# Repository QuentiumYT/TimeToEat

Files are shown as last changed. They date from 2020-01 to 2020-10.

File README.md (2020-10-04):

<h1 align="center">TimeToEat Project ⏰</h1>

Website (https://timetoeat.alwaysdata.net)&nbsp;
Donate (https://www.paypal.me/QuentiumYT/1)&nbsp;
Computer (https://www.raspberrypi.org/products/raspberry-pi-3-model-b/)&nbsp;
Tested on Python 3.5 (https://www.python.org/downloads)&nbsp;
Tested on Browsers&nbsp;
Application (https://timetoeat.alwaysdata.net/application/TimeToEat.apk)&nbsp;
Assets (https://www.solidworks.com/)&nbsp;
License&nbsp;
&nbsp;

## ✨ Introduction

<p align="center">
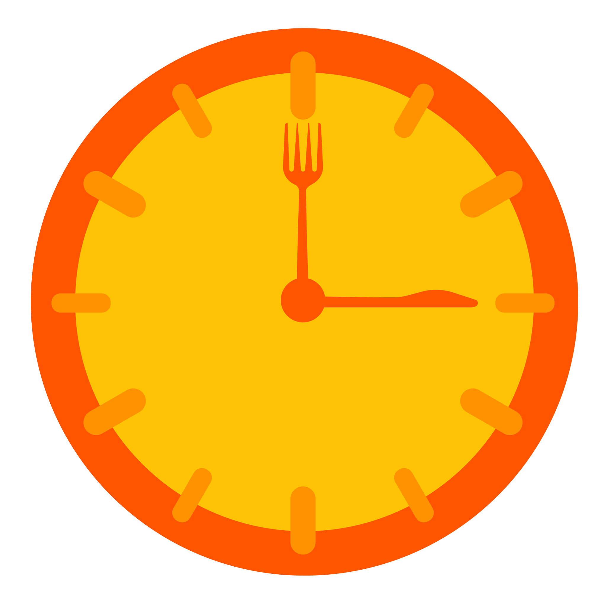
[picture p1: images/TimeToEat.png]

</p>

#### TimeToEat is a project for my final high school year exam (June 2019)

The idea for this project came to us when we noted the rather long waiting time in the canteen queue. So we decided to create a system to know the waiting time remaining as well as the number of people in the queue to be able to optimize its passage time.

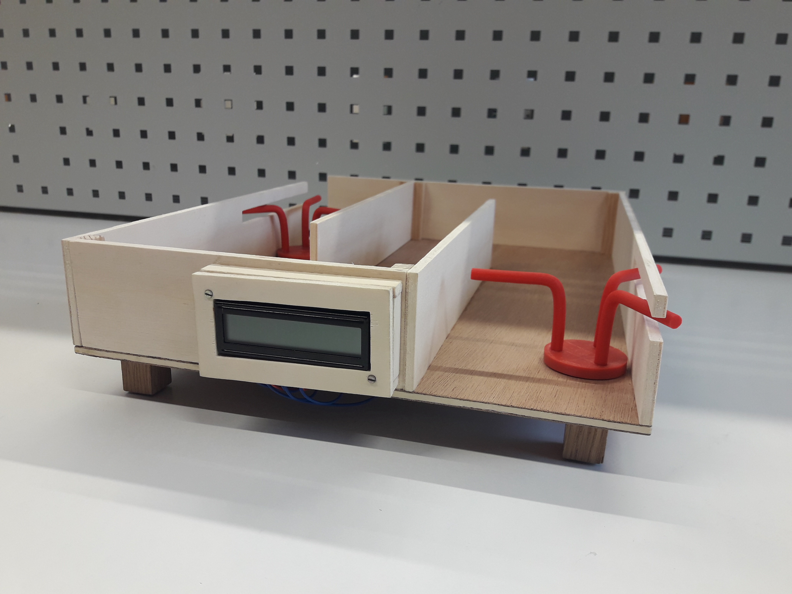
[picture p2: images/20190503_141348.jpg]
TimeToEat Model


You can find scripts `python/main.py` alongside `python/constantes.py` used on the raspberry to communicate with LCD and the [website](https://timetoeat.tk), you can always check the code but this project is very specific to a model we've made so you might find it useless.

This was a great first project with 2 of my close friends and we managed to get a good mark for this exam thanks to organization and work we've done :D

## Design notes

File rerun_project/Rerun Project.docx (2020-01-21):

Bonjour,

Je me permets de vous contacter pour vous joindre les fichiers de nôtre projet TimeToEat (en l’occurrence les miens) qui vous serviraient potentiellement à faire fonctionner le projet à nouveau.

Vu que la maquette se trouve encore au lycée, je me suis dit qu’il vous serait peut-être utile d’avoir un fonctionnement possible grâce aux fichiers et à la configuration de la Raspberry.

Si vous voulez donc remettre en marche ce projet, il vous faudra télécharger l’archive ci-jointe contenant les scripts pour la Raspberry (une image exacte de la Raspberry serait trop complexe à remettre en place car il risquerait d’y avoir des différences au niveau hardware).

MATERIEL RECOMMANDE :

-Raspberry pi 3

-Raspbian OS

-Carte SD : 4GB → Image sans desktop

8GB → Image avec desktop

CABLAGE DE LA MAQUETTE A LA RASPBERRY :

Vous trouverez l’image « TimeToEat_Wiring » ci-dessous pour avoir une vue d’ensemble, pour câbler la maquette il faut décaler le domino de 1 pin pour chacun des 2 (voir « TimeToEat_Brooch » pour la version simplifiée). La grosse broche (LCD) doit avoir le câble noir vers l’intérieur et la petite broche doit avoir le câble rouge vers l’extérieur.

CONFIGURATION RASPBERRY :

Si vous utilisez une nouvelle image de Rapsbian (téléchargement sur leur site), éditez /etc/dhcpcd.conf avec les paramètres réseaux (IP libre utilisée 10.129.104.127) puis communiquez avec WinSCP pour déplacer les fichiers joints dans l’archive RAR vers la raspberry (/home/pi/).

Vous devez déplacer « constantes.py » / « main.py » pour le fonctionnement mais aussi « pip.sh » et potentiellement « TimetoEat.sh » pour automatiser le fonctionnement instantané du projet.

Lancez Putty et installez les packages suivants :

AVEC « pip.sh » dans le dossier racine :

$ sudo bash pip.sh <nom du package>

SANS « pip.sh » dans le dossier racine :

$ sudo pip3 install --proxy=10.129.254.254:3128 <nom du package>

PACKAGES A INSTALLER :

« RPLCD » / « RPi.GPIO » / « requests » / « dotenv »

Si le package « RPi.GPIO » échoue, veuillez exécuter cette commande :

$ sudo apt-get -y install python3-rpi.gpio

Une fois les packages installés vous pouvez déjà lancer le projet, or, il vous faudra le relancer manuellement à chaque redémarrage de la raspberry.

DEMARRAGE MANUEL :

Tapez dans le terminal :

$ sudo python3 main.py

Le script devrait afficher des choses sur l’écran et commencer à tourner.

REDEMARRAGE AUTOMATIQUE :

Pour que le projet se lance au branchement secteur de la Raspberry, vous aurez besoin du package linux nommé « screen » :

- sudo apt-get -y install screen

Vous devrez ensuite posséder le fichier « TimeToEat.sh » dans le dossier racine (/home/pi/), dans ce cas, exécutez les commandes suivantes :

$ sudo mv TimeToEat.sh /etc/init.d/

$ cd /etc/init.d/

$ sudo chmod 777 TimeToEat.sh

$ sudo update-rc.d TimeToEat.sh defaults

Puis rebootez la Raspberry. S’il n’y a pas d’erreurs, tout devrait fonctionner comme à la soutenance de notre projet. Sinon, n’hésitez pas à me recontacter en cas de soucis.

Pour ce qui en est du site web, il sera toujours accessible via « https://timetoeat.alwaysdata.net/ » et restera actif via « https://timetoeat.xyz/ » jusqu’en mars (nom de domaine acheté bientôt expiré). Si le projet tourne, le seul changement sur le site sera dans la partie Temps réel.

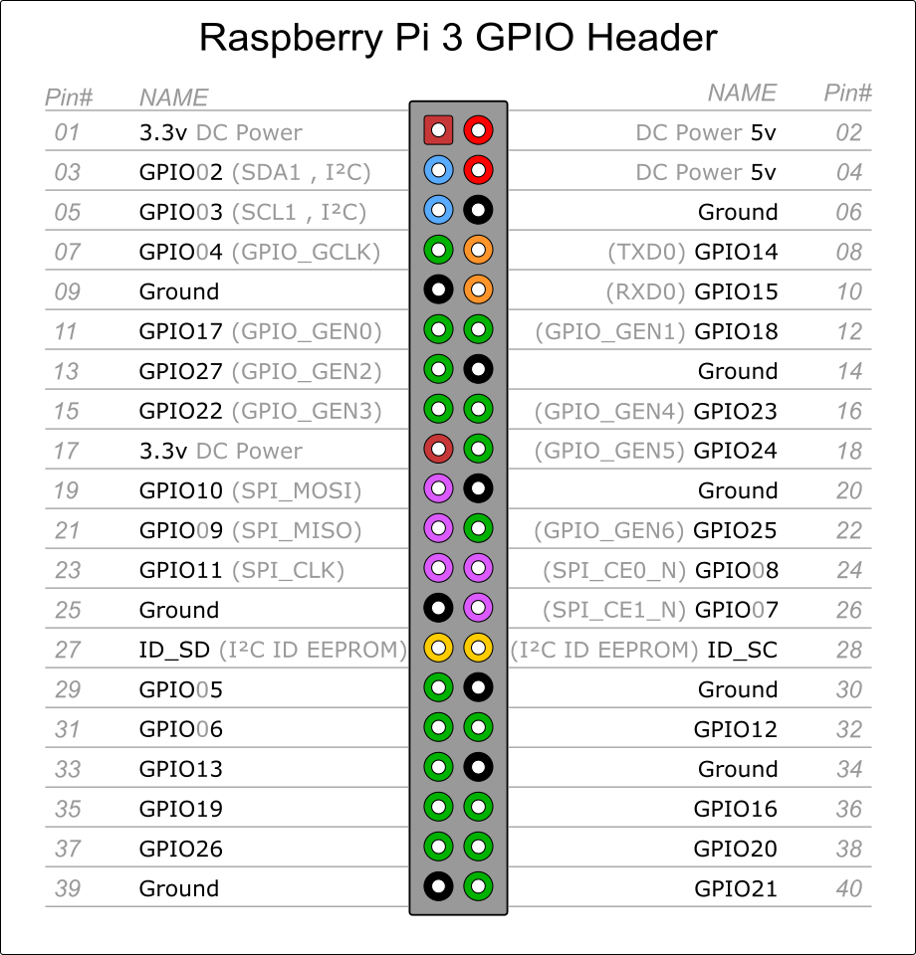
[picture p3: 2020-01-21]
images/Raspberry_Pi_GPIO_Layout.png

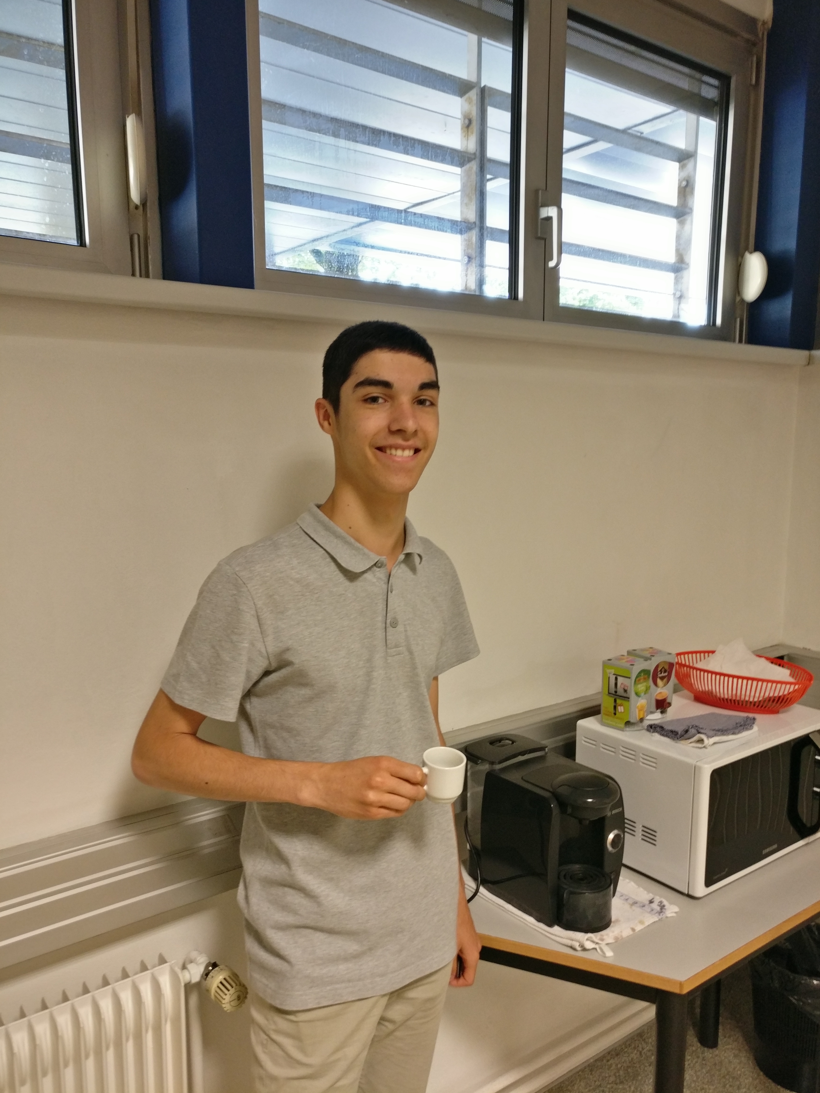
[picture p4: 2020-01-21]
web/img/quentin.jpg

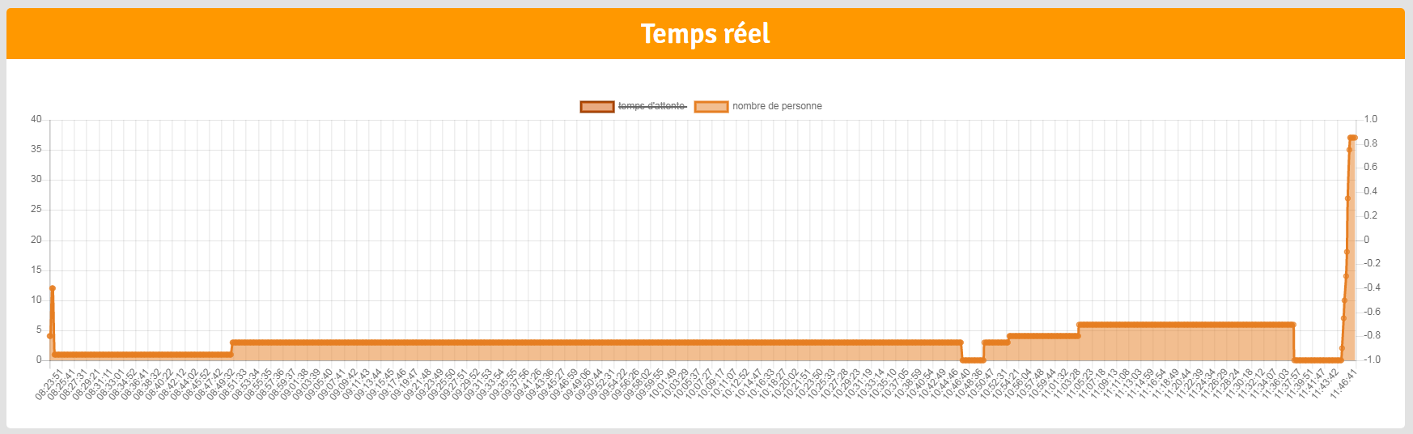
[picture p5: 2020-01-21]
images/Temps réel 2.png

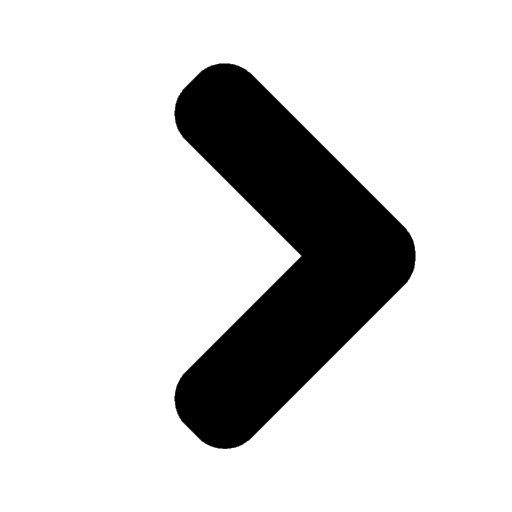
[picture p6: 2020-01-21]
web/img/arrow_right.png

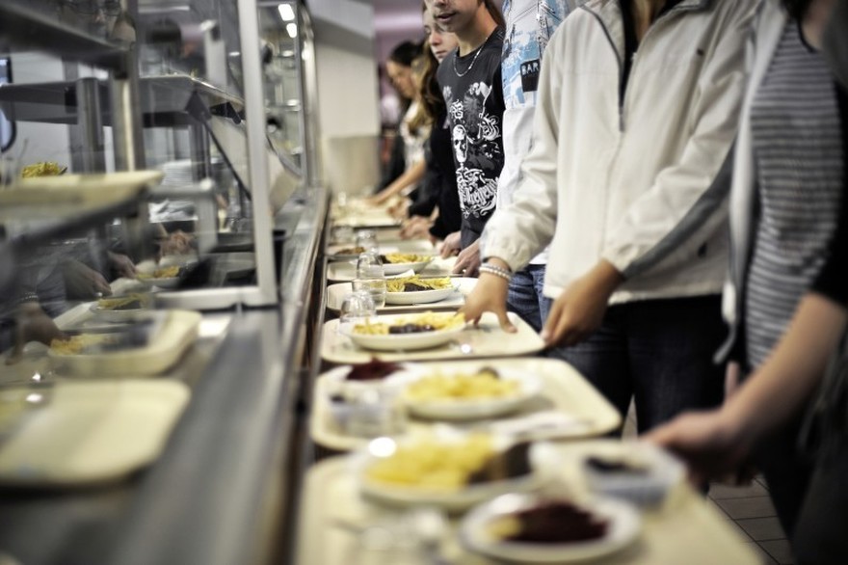
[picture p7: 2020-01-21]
web/img/cantine.jpg

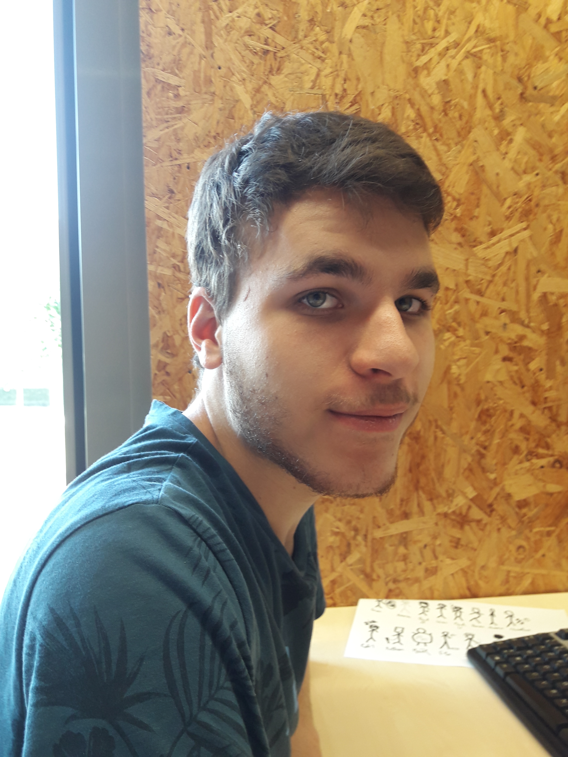
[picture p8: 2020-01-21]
web/img/nicolas.jpg

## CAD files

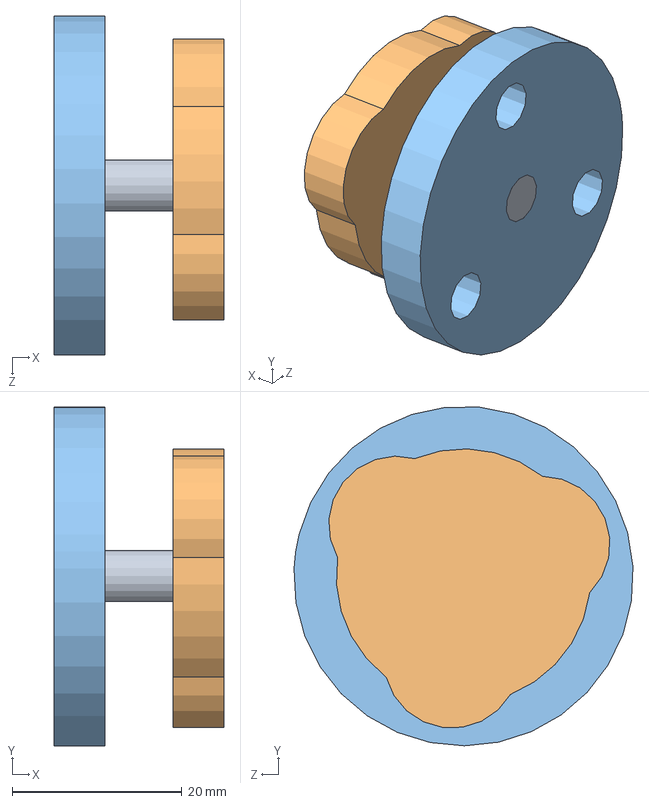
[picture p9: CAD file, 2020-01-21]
turnstile_solidworks/Assemblage2.SLDASM
20.0 x 39.9 x 39.9 mm
axe
came
tourniquet

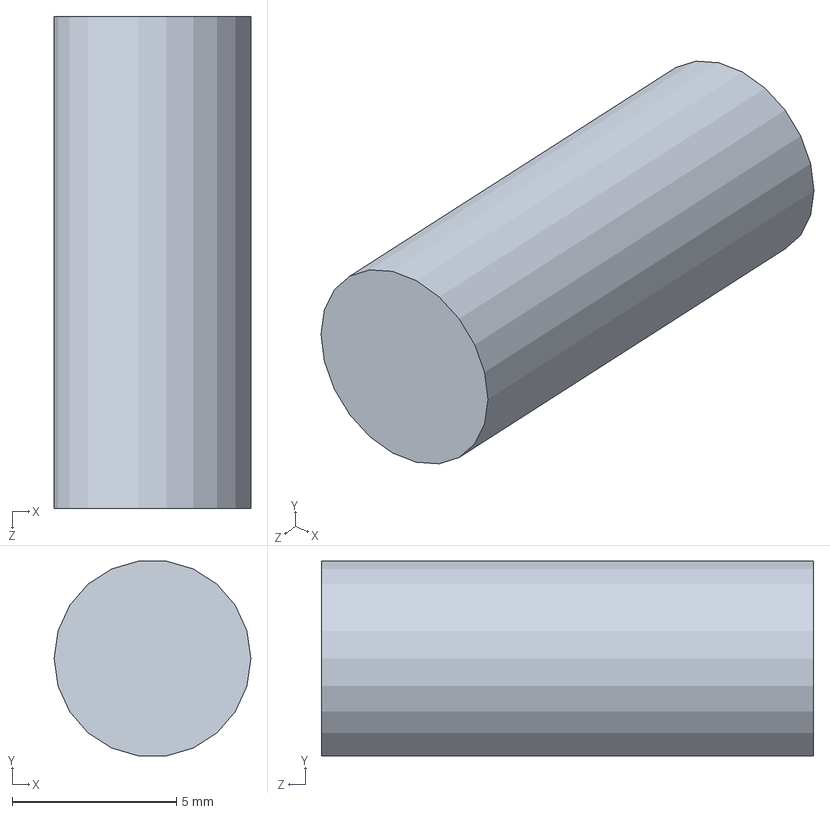
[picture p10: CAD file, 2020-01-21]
turnstile_solidworks/axe2.SLDPRT
6.00 x 5.94 x 15.0 mm

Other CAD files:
turnstile_solidworks/Module.SLDASM
turnstile_solidworks/mur-central.SLDPRT
turnstile_solidworks/Microrupteur.SLDPRT
turnstile_solidworks/sol.SLDPRT
turnstile_solidworks/tourniquet.SLDPRT
turnstile_solidworks/mur-exterieur.SLDPRT
turnstile_solidworks/mur2.SLDPRT
turnstile_solidworks/mur1.SLDPRT
turnstile_solidworks/barre-de-passage.SLDPRT
turnstile_solidworks/came.SLDPRT
turnstile_solidworks/axe.SLDPRT
turnstile_solidworks/axe2.STL

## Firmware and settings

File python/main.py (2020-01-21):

from RPLCD import CharLCD # Module pour l'ecran LCD
from RPi import GPIO # Module pour les pins
from datetime import datetime # Module pour le temps (timer)
import threading, time, calendar, requests, random # Autres modules complémentaires

from constantes import * # Importation des constantes / pins / charactères spéciaux

# Réglages pour GPIO
GPIO.setwarnings(False)
GPIO.setmode(GPIO.BOARD)
GPIO.setup(pins_data_count, GPIO.IN, pull_up_down=GPIO.PUD_DOWN) # Mode des microrupteurs

# Définition de l'écran LCD
lcd = CharLCD(numbering_mode=GPIO.BOARD,
              cols=16, rows=2, pin_rs=37, pin_e=35,
              pins_data=pins_data_lcd, charmap="A02")

# Fonction de cryptage
def cryptage(chaine, cle):
    global alpha
    liste = ""
    for caractere in chaine:
        try:
            index = alpha.index(caractere)
            numero = index + cle
            cle = cle + cle
            if cle > len(alpha) - 1:
                cle = cle - len(alpha) - 1
            if numero > len(alpha) - 1:
                numero = numero - len(alpha)
            liste += alpha[numero]
        except:
            liste += caractere
    return liste

# Affichage des données sur l'écran LCD
def write_on_lcd(nb_people, nb_flow, state):
    global old_nb_people, old_nb_flow
    lcd.clear()
    lcd.cursor_pos = (0, 0) # Position initiale
    if state == "+": # Personne rejoins
        state = " \2"
    elif state == "-": # Personne quitte
        state = " \3"
    elif state == "*": # Débit affiché
        state = " \4"
    if not nb_people == "None":
        lcd.write_string("Personnes: " + str(nb_people) + state)
        old_nb_people = nb_people #Définition de l'ancienne valeur des personnes
    else:
        lcd.write_string("Personnes: " + str(old_nb_people) + state)
    lcd.cursor_pos = (1, 0)
    if not nb_flow == "None":
        lcd.write_string("D\1bit: {}/min".format(str(nb_flow)))
        old_nb_flow = nb_flow # Définition de l'ancienne valeur du débit
    else:
        lcd.write_string("D\1bit: {}/min".format(str(old_nb_flow)))
    lcd.write_string(" \0")

def init():
    global count_people, count_people_leave, count_people_leave_now, old_nb_people, old_nb_flow, signal_button
    # Définition des variables par défaut
    count_people = count_people_leave = 0
    count_people_leave_now = 0
    old_nb_people = old_nb_flow = 0
    signal_button = 0
    # Création des caractères spéciaux
    lcd.create_char(0, logo)
    lcd.create_char(1, e_aigu)
    lcd.create_char(2, arrow_up)
    lcd.create_char(3, arrow_down)
    lcd.create_char(4, arrow_none)
    # Initialisation de l'écran LCD
    lcd.clear()
    lcd.cursor_pos = (0, 0)
    lcd.write_string("Personnes: --")
    lcd.cursor_pos = (1, 0)
    lcd.write_string("D\1bit: --/min")
    lcd.write_string(" \0")

# Définition du timer en thread pour gérer le comptage et envoyer les données
def timer_every_minute():
    global count_people, count_people_leave, count_people_leave_now
    now = datetime.today().replace(microsecond=0)
    num_days_month = calendar.monthrange(int(now.strftime("%y")), int(now.strftime("%m")))[1]
    clock = now.replace(day=now.day, hour=now.hour, minute=now.minute, second=0, microsecond=0)
    if now.minute == clock.minute:
        if not int(now.minute) == 59:
            clock = now.replace(day=now.day, hour=now.hour, minute=now.minute + 1, second=0, microsecond=0)
        else:
            clock = now.replace(day=now.day, hour=now.hour + 1, minute=0, second=0, microsecond=0)

    while True:
        time_now = datetime.today().replace(microsecond=0)
        timer_finished = time_now
        sec_time = int(time_now.strftime("%S"))
        min_time = int(time_now.strftime("%M"))
        hour_time = int(time_now.strftime("%H"))
        day_time = int(time_now.strftime("%d"))
        if sec_time > 50 and sec_time <= 59:
            if min_time == 59:
                if hour_time == 23:
                    if day_time == num_days_month:
                        timer_finished = time_now.replace(month=time_now.month + 1, day=1, hour=0, minute=0, second=0)
                    else:
                        timer_finished = time_now.replace(day=time_now.day + 1, hour=0, minute=0, second=0)
                else:
                    timer_finished = time_now.replace(hour=time_now.hour + 1, minute=0, second=0)
            else:
                timer_finished = time_now.replace(minute=time_now.minute + 1, second=0)
        print(clock, time_now)
        if timer_finished == clock:
            print(count_people_leave, "people per minute")
            write_on_lcd("None", count_people_leave, "*")
            #send_data_web(count_people, count_people_leave)
            count_people_leave = 0 # Reset du débit
            now = datetime.today().replace(microsecond=0)
            if min_time == 59:
                if hour_time == 23:
                    clock = now.replace(day=now.day + 1, hour=0, minute=1, second=0, microsecond=0)
                else:
                    clock = now.replace(hour=now.hour + 1, minute=1, second=0, microsecond=0)
            else:
                clock = now.replace(minute=now.minute + 2, second=0, microsecond=0)
        time.sleep(10)
        send_data_web_now(count_people, count_people_leave_now)
        count_people_leave_now = 0

# Fonction d'envoi de données pour un cycle cantine
def send_data_web(count_people, count_debit):
    random_key = random.randint(10, len(alpha)) # Clé aléatoire
    count_crypt = cryptage(str(count_people), int(random_key)) # Cryptage du nombre de personnes
    debit_crypt = cryptage(str(count_debit), int(random_key)) # Cryptage du nombre du débit
    payload = "?count=" + count_crypt + "&debit=" + debit_crypt + "&key=" + str(random_key) # Données dans l'URL
    requests.get(url + payload, proxies=proxyDict) # Envoi des données avec proxy

# Fonction d'envoi de données en temps réel
def send_data_web_now(count_people, count_debit):
    random_key = random.randint(10, len(alpha)) # Clé aléatoire
    count_crypt = cryptage(str(count_people), int(random_key)) # Cryptage du nombre de personnes
    debit_crypt = cryptage(str(count_debit), int(random_key)) # Cryptage du nombre du débit
    payload = "?count_now=" + count_crypt + "&debit_now=" + debit_crypt + "&key_now=" + str(random_key) # Données dans l'URL
    requests.get(url + payload, proxies=proxyDict) # Envoi des données avec proxy

# Définition du thread pour gérer le timer et le comptage de données en même temps
def start_thread():
    thread = threading.Thread(target=timer_every_minute)
    thread.daemon = True # Deamon permet d'arreter le thread en cas de CTRL-C
    thread.start()

    def on_join(): # Simple comptage
        global count_people
        count_people += 1
        write_on_lcd(count_people, "None", "+")
        print("1 people joined ({} people waiting)".format(count_people))

    def on_leave(): # Décomptage + débit
        global count_people, count_people_leave, count_people_leave_now
        if not count_people <= 0:
            count_people -= 1
            count_people_leave += 1
            count_people_leave_now += 1
            write_on_lcd(count_people, "None", "-")
            print("1 people left ({} people waiting)".format(count_people))
        else:
            count_people = 0
            write_on_lcd(count_people, "None", "*")

    while True: # Boucle infinie pour relever les données
        time.sleep(0.001)
        if GPIO.input(8):
            if signal_button == 1 or signal_button == 3:
                signal_button = 2
                on_join()
        elif GPIO.input(10):
            if signal_button == 1 or signal_button == 2:
                signal_button = 3
                on_leave()
        else:
            signal_button = 1

if __name__ == "__main__":
    init()
    # Démarrage du thread pour le timer en meme temps que le comptage
    start_thread()

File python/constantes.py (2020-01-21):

import string

# Configuration des pins microrupteurs
pins_data_count = [8, 10]
# Configuration des pins LCD
pins_data_lcd = [33, 31, 29, 23]
# URL du site web
url = "http://timetoeat.alwaysdata.net/index.php"
# Alphabet pour le chiffrement des données
alpha = string.ascii_letters + string.digits

# Definition du proxy pour les requetes
proxyDict = {
    "http": "http://10.129.254.254:3128",
    "https": "https://10.129.254.254:3128"
}

logo = ( # Logo TimeToEat
    0b00000,
    0b01110,
    0b10101,
    0b10111,
    0b10001,
    0b01110,
    0b00000,
    0b00000
)

e_aigu = ( # Caractère "é"
    0b00010,
    0b00100,
    0b01110,
    0b10001,
    0b11111,
    0b10000,
    0b01110,
    0b00000
)

arrow_up = ( # Caractère Flèche haute
    0b00000,
    0b00100,
    0b00100,
    0b01110,
    0b01110,
    0b11111,
    0b11111,
    0b00000
)

arrow_down = ( # Caractère Flèche basse
    0b00000,
    0b11111,
    0b11111,
    0b01110,
    0b01110,
    0b00100,
    0b00100,
    0b00000
)

arrow_none = ( # Caractère Flèche neutre
    0b00000,
    0b00000,
    0b00000,
    0b11111,
    0b11111,
    0b00000,
    0b00000,
    0b00000
)

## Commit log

2020-01-21 TimeToEat project for my final school year exam (2019)
    [Assemblage2.SLDASM, Microrupteur.SLDPRT, Module.SLDASM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]
2020-09-30 Reorganised files (Python + Raspberry)
2021-03-07 CSS global margin / padding reset, button and img unneeded style

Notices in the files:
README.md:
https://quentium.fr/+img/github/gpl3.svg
